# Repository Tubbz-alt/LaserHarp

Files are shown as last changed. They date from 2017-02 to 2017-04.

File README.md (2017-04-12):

# LaserHarp
The laser harp is a harp that uses lasers in place of strings. It is built to visually resemble a harp, consisting of a rectangular wooden frame and a set of 8 “strings”. Each “string” is a beam of an independent downward-pointing laser diode. A string is “plucked” by breaking the laser beam (most often with a hand, but it could be any object). There are sensors for each laser beam that detect when the beam has been broken. An Arduino board constantly reads out the sensors and if it detects an “pluck” event it will generate a sound. 

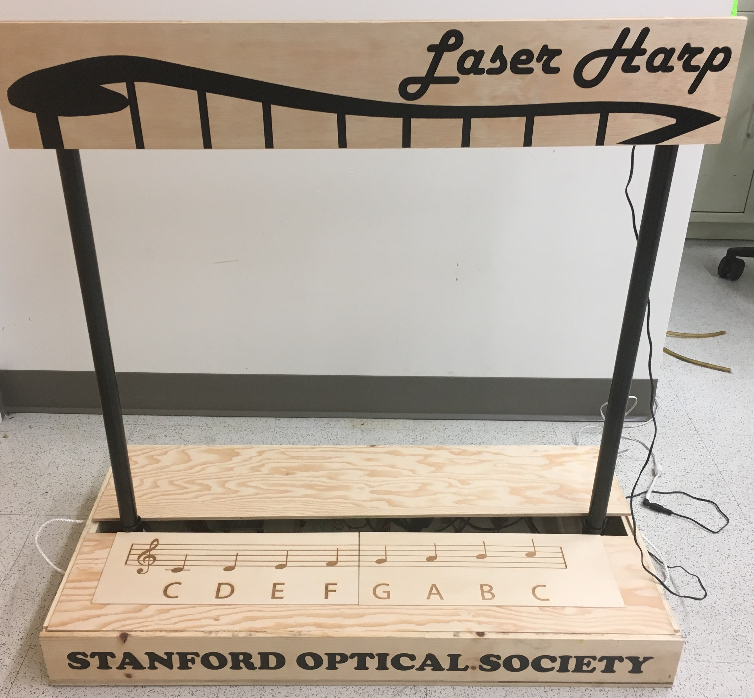
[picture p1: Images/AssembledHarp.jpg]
Assembled Laser Harp


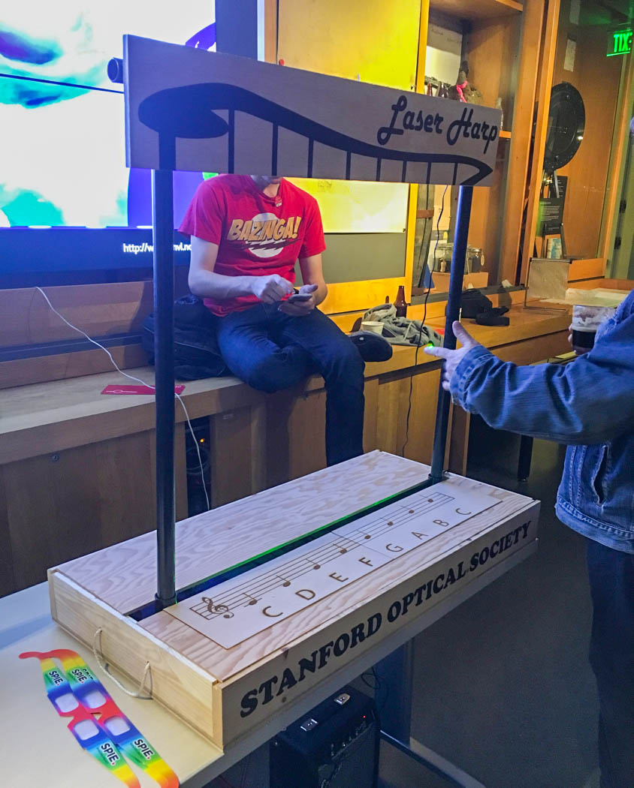
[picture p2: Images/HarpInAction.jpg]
Laser Harp in action


The laser harp works best in constant lighting conditions with the cover closed, as the laser beams will provide cleaner visual feedback when reflected off the harpist’s hands. Fog machines can also help visualize the beams but too much fog can trigger the harp sounds (the beam becomes too scattered and the sensors detect that as a broken beam).

It is a fun interactive demo suitable for all ages.

## [Assembly Instructions](https://github.com/mcleung/LaserHarp/blob/master/AssemblyInstructions.md)

## [Constructing your own Harp](https://github.com/mcleung/LaserHarp/blob/master/ConstructionInstructions.md)

# Credits
Thanks to everyone in the Stanford Optical Society for helping me build this, and to previous members who built the first version of the laser harp!

You can learn more about the Stanford Optical Society, and all of the work that we do at https://photons.stanford.edu

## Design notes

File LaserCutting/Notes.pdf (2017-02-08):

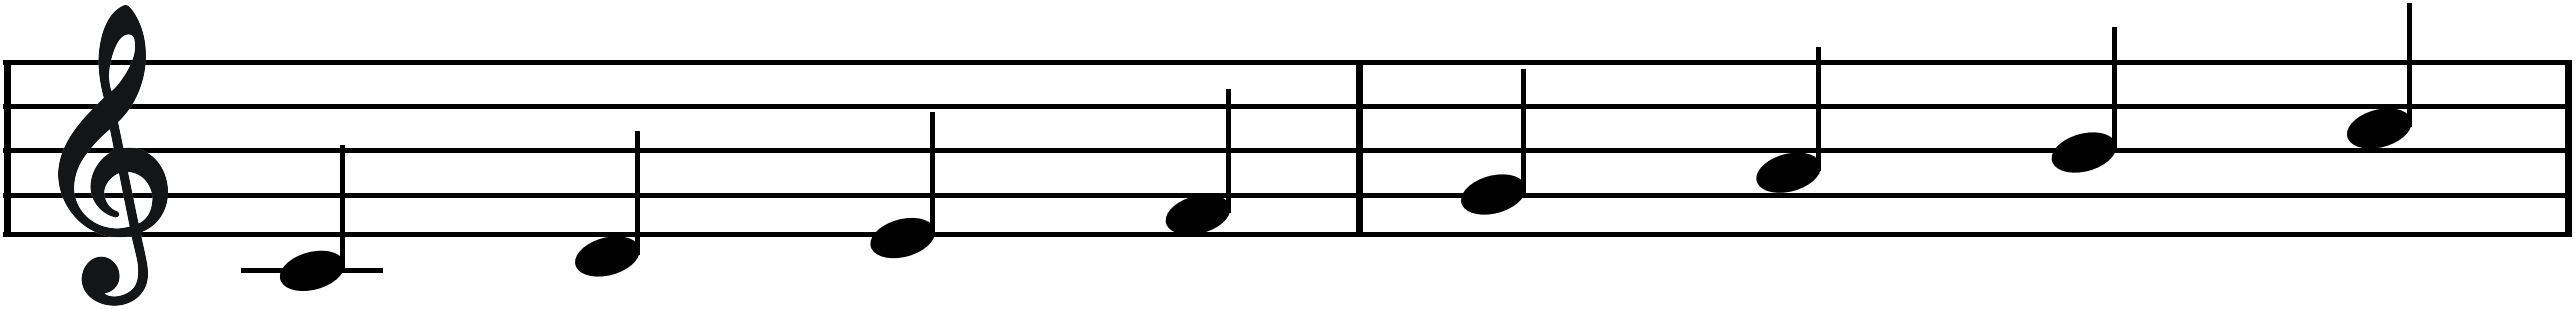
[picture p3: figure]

C D E F G A B C

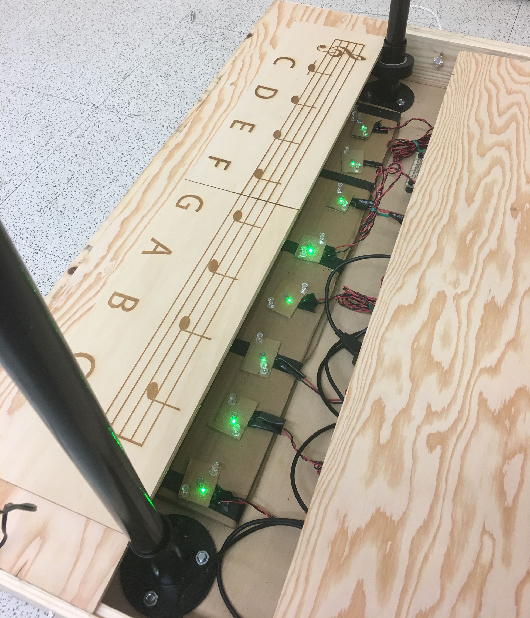
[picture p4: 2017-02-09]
Images/LaserDetectors.jpg

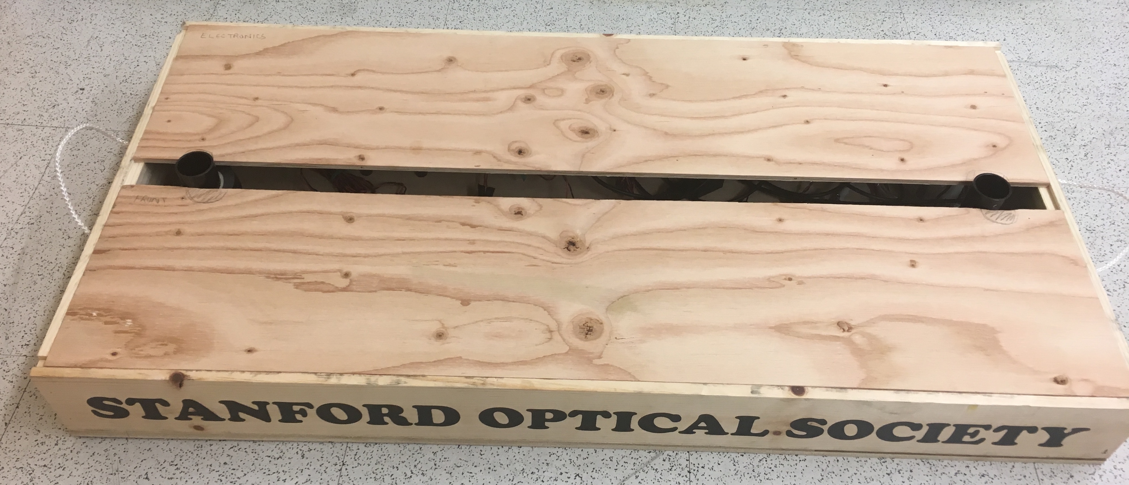
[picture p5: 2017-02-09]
Images/CompactHarp.jpg

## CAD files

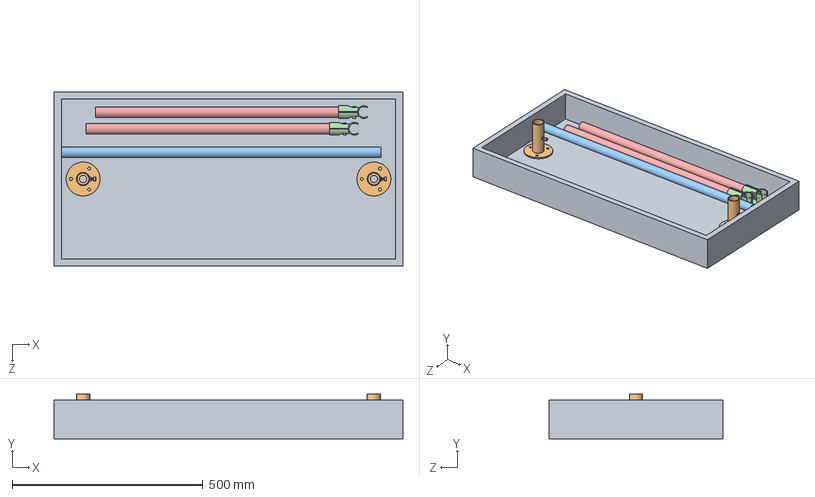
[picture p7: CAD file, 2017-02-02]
Mechanical/SolidWorks/1001-Transport.SLDASM
914.4 x 117.3 x 457.2 mm
6001-Base
6005-ClampFitting x 2
6020-PipeTop
6015-ClampOpen x 2
6010-PipeSide x 2

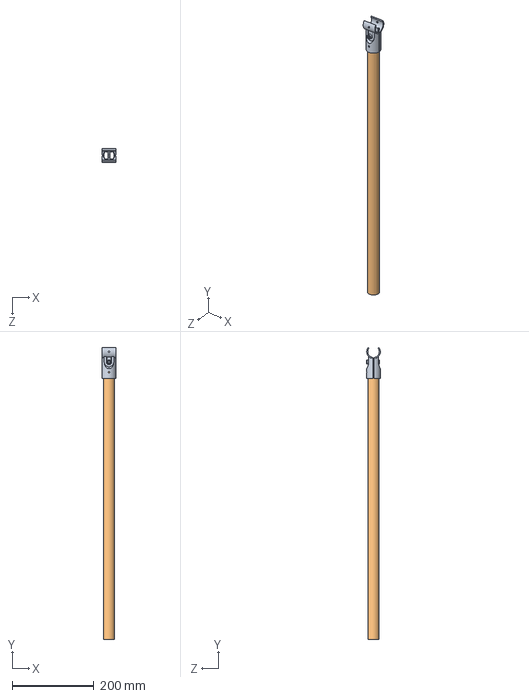
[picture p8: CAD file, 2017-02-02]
Mechanical/SolidWorks/1120-Post.SLDASM
33.5 x 713.4 x 33.8 mm
6015-ClampOpen
6010-PipeSide

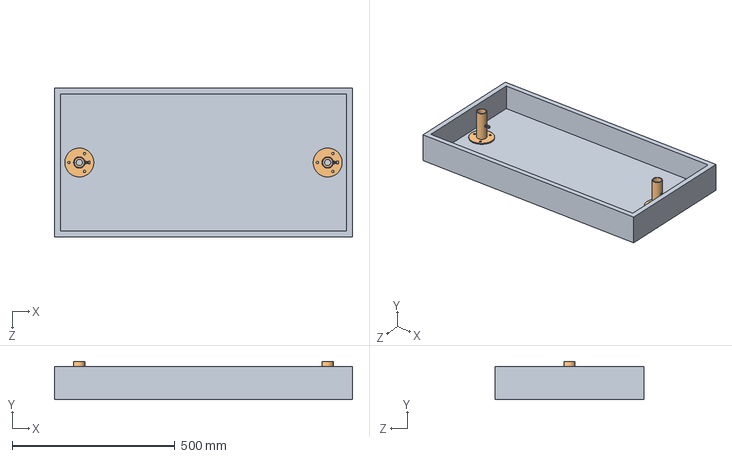
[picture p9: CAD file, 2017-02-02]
Mechanical/SolidWorks/1100-BaseAsm.SLDASM
914.4 x 117.3 x 457.2 mm
6001-Base
6005-ClampFitting x 2

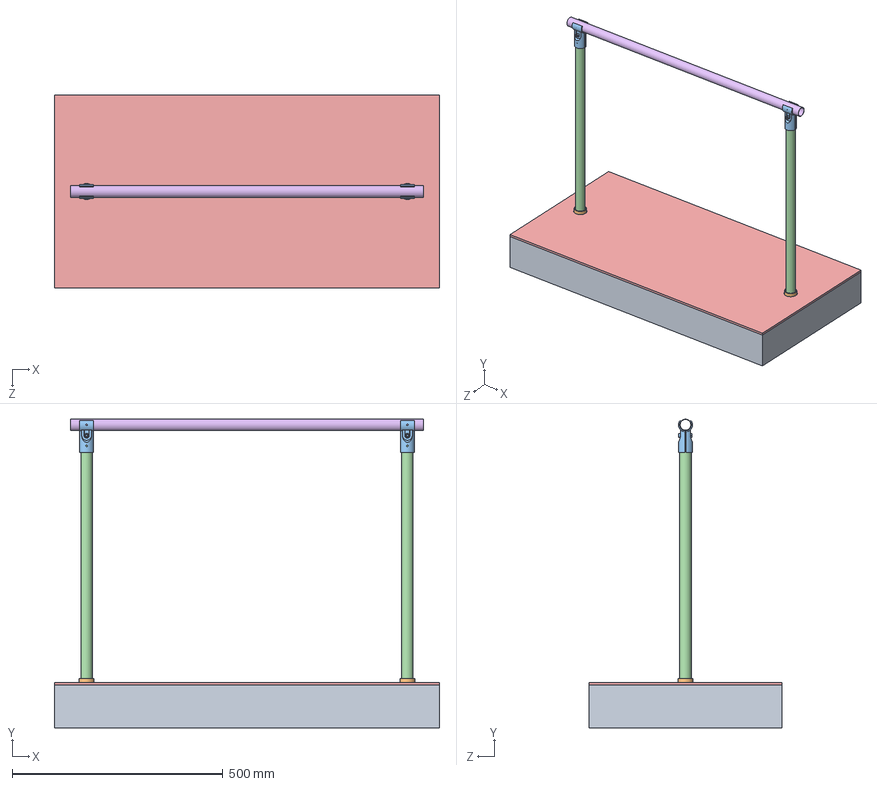
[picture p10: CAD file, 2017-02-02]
Mechanical/SolidWorks/1000-Assembled.SLDASM
914.4 x 733.5 x 457.2 mm
6001-Base
6005-ClampFitting x 2
6015-ClampOpen x 2
6010-PipeSide x 2
6003-BaseTop
6020-PipeTop

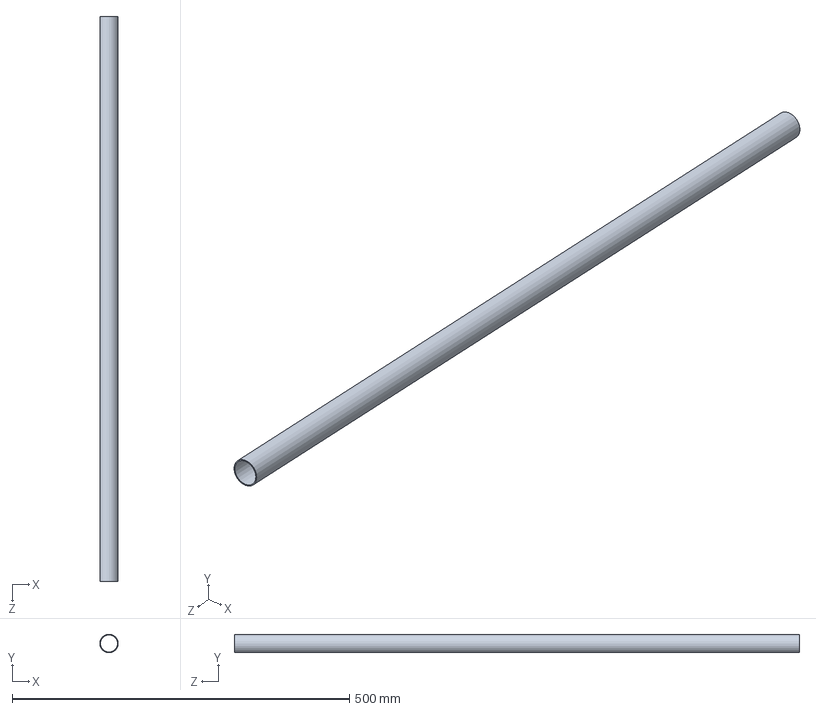
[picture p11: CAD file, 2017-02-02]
Mechanical/SolidWorks/1150-TopAsm.SLDASM
27.4 x 27.4 x 838.2 mm

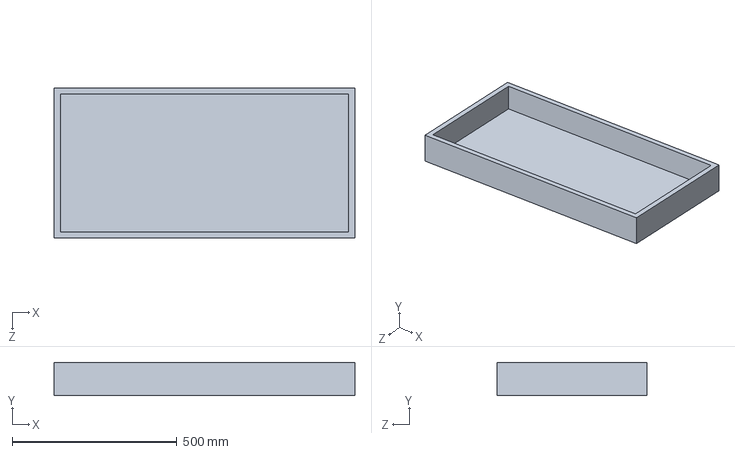
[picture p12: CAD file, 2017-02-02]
Mechanical/SolidWorks/6001-Base.SLDPRT
914.4 x 101.6 x 457.2 mm

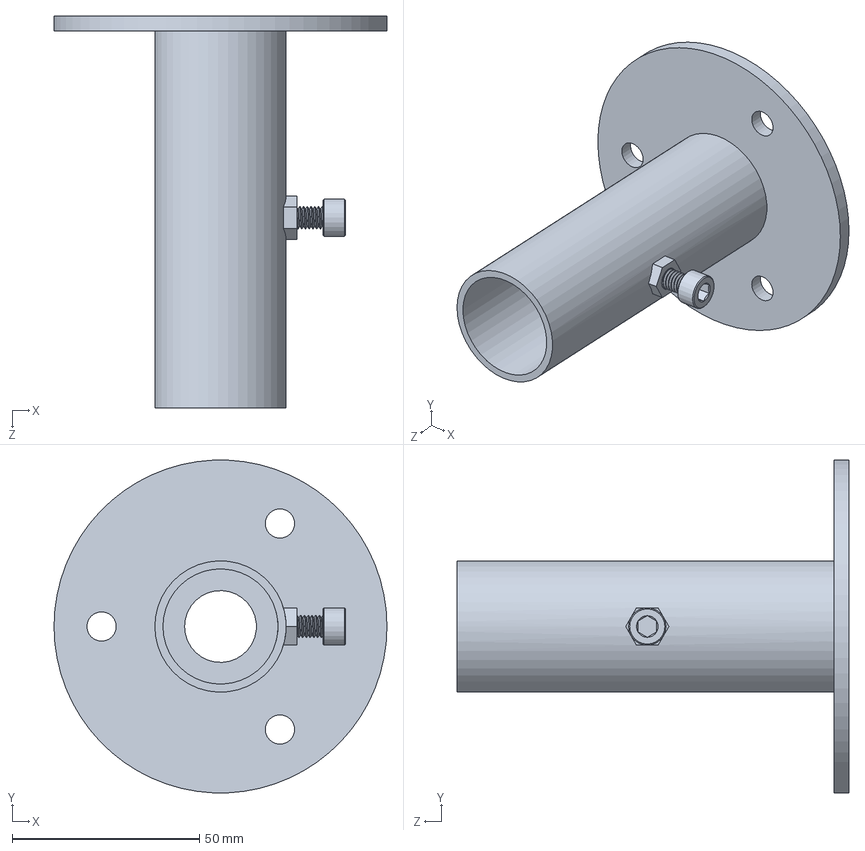
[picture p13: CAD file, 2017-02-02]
Mechanical/SolidWorks/6005-ClampFitting.SLDPRT
88.9 x 88.8 x 104.6 mm

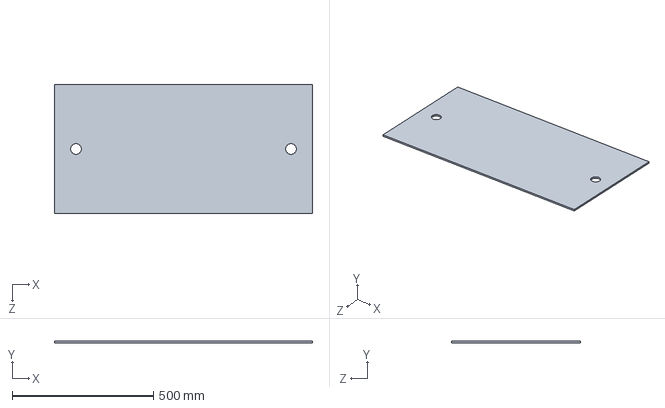
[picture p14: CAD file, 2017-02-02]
Mechanical/SolidWorks/6003-BaseTop.SLDPRT
914.4 x 6.35 x 457.2 mm

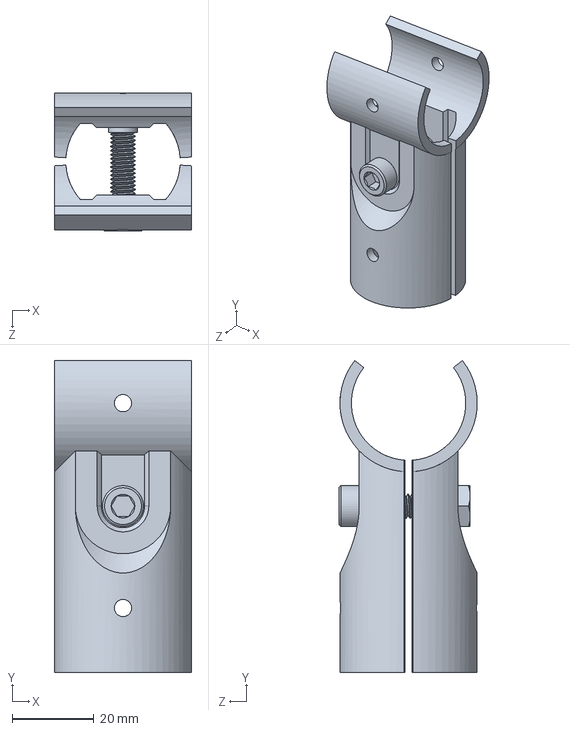
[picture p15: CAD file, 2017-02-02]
Mechanical/SolidWorks/6015-ClampOpen.SLDPRT
33.5 x 76.2 x 33.8 mm

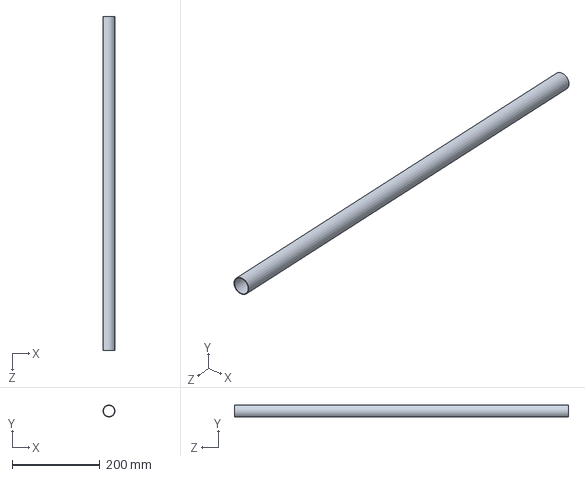
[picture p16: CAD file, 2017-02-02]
Mechanical/SolidWorks/6010-PipeSide.SLDPRT
27.4 x 27.4 x 762.0 mm

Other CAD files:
Mechanical/SolidWorks/6020-PipeTop.SLDPRT
Mechanical/SolidWorks/6023-TopPlate.SLDPRT

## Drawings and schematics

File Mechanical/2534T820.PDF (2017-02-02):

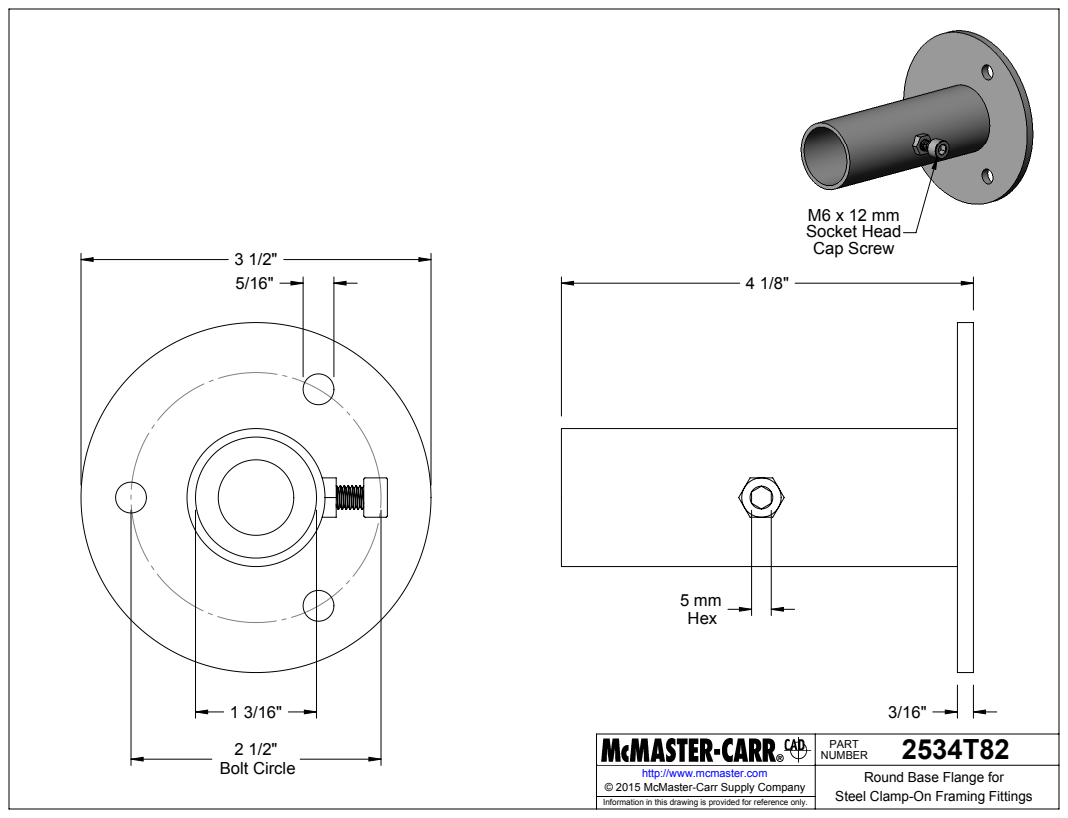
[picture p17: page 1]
2 1/2" Bolt Circle; M6 x 12 mm Socket Head Cap Screw

2534T82 PART NUMBER

http://www.mcmaster.com | Round Base Flange for Steel Clamp-On Framing Fittings © 2015 McMaster-Carr Supply Company

Information in this drawing is provided for reference only.

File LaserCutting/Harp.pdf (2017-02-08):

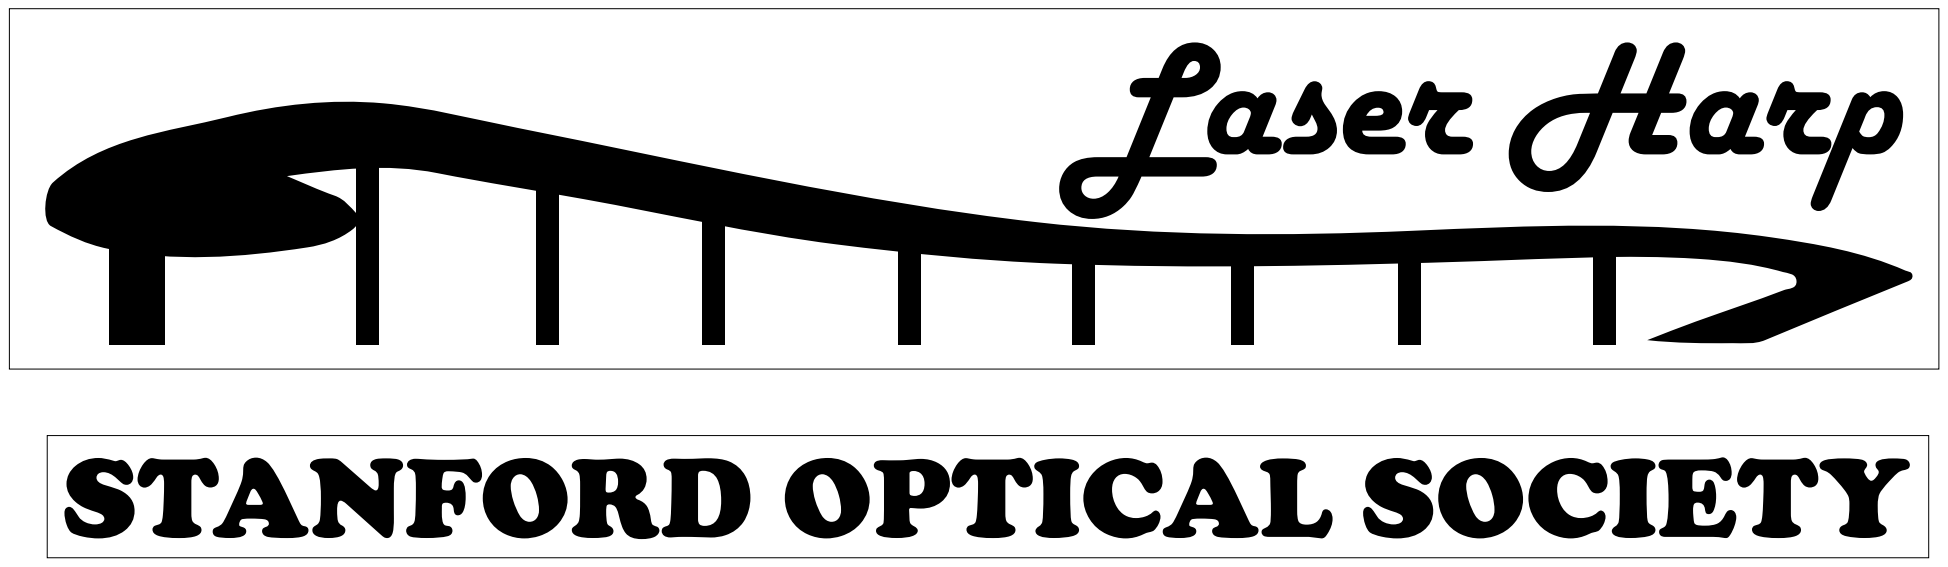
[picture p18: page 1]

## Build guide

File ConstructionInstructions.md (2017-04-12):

# Constructing your own harp
The material list and instructions below are for exactly replicating the laser harp built by Stanford OSA, but note that materials and processes can be changed to your liking. For example, the box is currently made from wood pieces commonly found at any hardware improvement store (e.g., Home Depot), but it could be replaced with any number of other materials and/or thicknesses.
Where applicable, we have included part numbers from specific manufacturers. 

## Materials Needed

### Wooden Frame
- Plywood:
  - 1 piece: 36 x 18 x 0.5 inch (base)
  - 1 piece: 33 x 10 x 0.5 inch (top crossbar)
  - 2 pieces: 35.5 x 8.5 x 0.25 inch (cover)
- Pine wood:
  - 2 pieces: 1 x 4 x 36 inch (long sidewalls)
  - 2 pieces: 1 x 4 x 16.5 inch (short sidewalls)
- Around 20 pieces: 1.5” wood screws to hold wood together
- Plastic-coated steel rail, 1 inch OD (McMaster Carr: [2534T13](https://www.mcmaster.com/#catalog/123/1964/=175omqx))
  - 2 pieces: 30 inches in length (side bars)
  - 1 piece: 32 inches in length (for crossbar)
- 2 pieces: round flange rail end (McMaster Carr: [2534T82](https://www.mcmaster.com/#catalog/123/1964/=175omfq))
- 2 pieces: open tee rail connector (McMaster Carr: [2534T22](https://www.mcmaster.com/#catalog/123/1964/=175omb7))
- 6 pieces: Carriage bolts and nuts (McMaster Carr: [93180A220](https://www.mcmaster.com/#carriage-bolts/=1760sma))
- 2 pieces: Routing clamps (McMaster Carr: [8874T43](https://www.mcmaster.com/#pipe-routing-clamps/=1760tv2))
- Wood glue

Note: decorations are made using a laser cutter and vinyl cutter

### Electronics
- 8 pieces: 5mW 532nm laser diodes (color is not important, but they should operate on 5V power supply. We used [these ones](https://m.dhgate.com/product/50mw-532nm-green-laser-diode-module-line/158930720.html))
- 8 pieces: Routing Clamps or other mounting hardware to attach lasers onto the crossbar. (McMaster Carr: [8874T14](https://www.mcmaster.com/#pipe-routing-clamps/=1760xm5))
- 16 pieces: screws for attaching conduit straps (should not be thicker than the crossbar, we used ⅜)
- Power supply for the lasers. We recommend a 1.5 to 2A supply (each laser uses ~100mA of power; we assume: 8 * 100mA + safety factor (Digikey: [993-1296-ND](https://www.digikey.com/product-detail/en/phihong-usa/PSC15A-050/993-1296-ND/5247140))
- Arduino Nano v3 (Digikey: [1050-1001-ND](https://www.digikey.com/product-detail/en/arduino/A000005/1050-1001-ND/2638989))
- MP3/audio board compatible with the Arduino (Gravitech: [MP3-4NANO](http://www.gravitech.us/mp3pladforar.html))
- Breadboard
- 8 pieces: photo-resistors (SparkFun: [SEN-09088](https://www.sparkfun.com/products/9088))
- 8 pieces: 10kOhm resistors
- USB power supply, including cable (used to power the arduino + audio board)
- Audio cable (3.5mm male to male)
- Guitar amp with a 3.5mm line in port
- Various wires to connect everything
- Electrical tape
- Cardboard
- Push pins

## Constructing the wooden frame

Below is an image from the 3D modeling of the wooden frame. The files can be find in the links at the end of the document. 
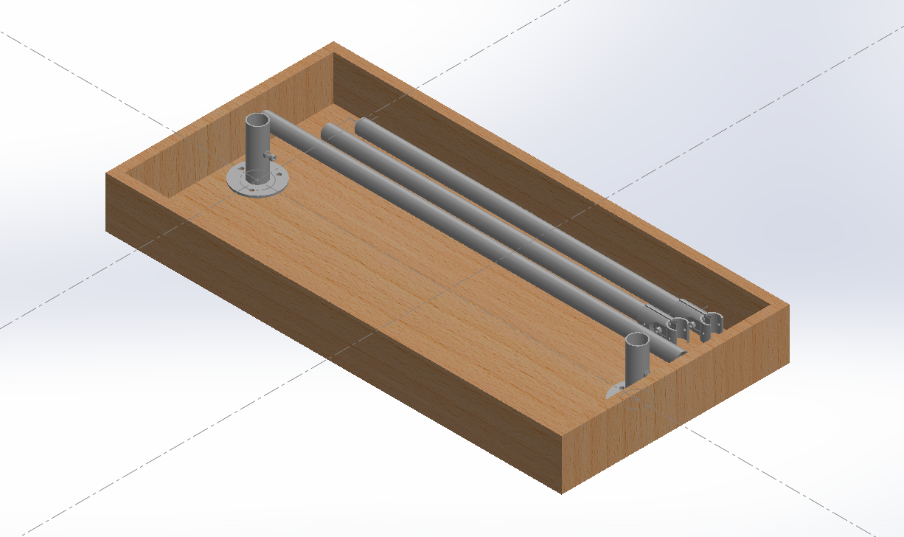
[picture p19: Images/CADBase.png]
CAD Base


1. Cut all wooden pieces to the sizes specified in the materials list.
2. Create a 0.25 x 0.25 inch notch in each sidewall so that the top cover piece fits nicely inside.
3. Use wood glue to attached the side walls to the base piece.
Secure each side wall to the base with screws (4 screws for the long sides and 2 screws for the short sides).
4. Using the carriage nuts and bolts attach the rail ends to the base of the box (centered in the box and separated by 30 inches).
5. Attach open tee rail connectors to the 30 inch pieces of rail. 
6. Fix the longer rail (32 inches) to the plywood used for the crossbar using conduit straps. 

For decorations (all files are available in the link at the end of the document):
1. Laser cut the staff pattern onto the sheet wood. If the bed of the laser cutter cannot fit the entire piece then you can split the staff into two parts. This is what we did for our laser harp. 
2. Vinyl cut the patterns for the top of the laser harp and affix to the crossbar. 

Notes:
- All the rail pieces, including the tee on the side bars, should be sized to fit within the box.
- The cover simply lays on top of the box. Alternatively, the top piece could be screwed into position or hinges could be used. 

## Constructing the software
  The latest version of the Arduino code is found on this [Github repository](https://github.com/mcleung/LaserHarp/tree/master/Arduino/LaserHarp). If you have any changes or suggestions, please let us know so we can update it!

## Constructing the electronics
1. Upload Arduino code found on this [Github repository](https://github.com/mcleung/LaserHarp/tree/master/Arduino/LaserHarp).

2. Connect Arduino onto the MIDI shield.

3. Connect midi shield output to speakers.

4. Evenly space and secure all lasers to the crossbar using conduit straps. We found that something between 1.5 to 2.5 inches works well.

5. Solder all the laser power supplies in parralel, and connect to the 5V 2A supply.

6. Affix each photoresistor to a small piece of cardboard.

7. Photoresistors should be connected to the Arduino as active low (pull-up) sensors. They should be wired as follows. 5V supply - 10k resistor(or other pull up resistor) - wire connecting back to Analog input - photoresistor - ground.

8. Turn on the lasers by connecting the power supply, and align detectors on cardboard piece.

9. Using the push pins, attached the cardboard/photoresistor to  larger piece of cardboard. The push pins give the flexibility to move the photoresistors for alignment with the lasers. 
  Beware! Avoid staring into the laser or direct reflections. Remove all jewlery and other shiny accessories.

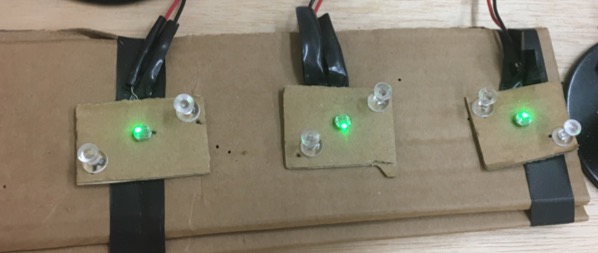
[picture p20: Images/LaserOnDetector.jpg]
Laser aligned on photoresistor


Notes:
  The chip on the audio board does not just support MP3 but also synthesizing sound based on MIDI commands. We are generating MIDI signals with the Arduino and playing them with the audio board.

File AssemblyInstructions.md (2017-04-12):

# Assembly Instructions

## Materials required

Laser Harp box containing electronics and power supply (See image)

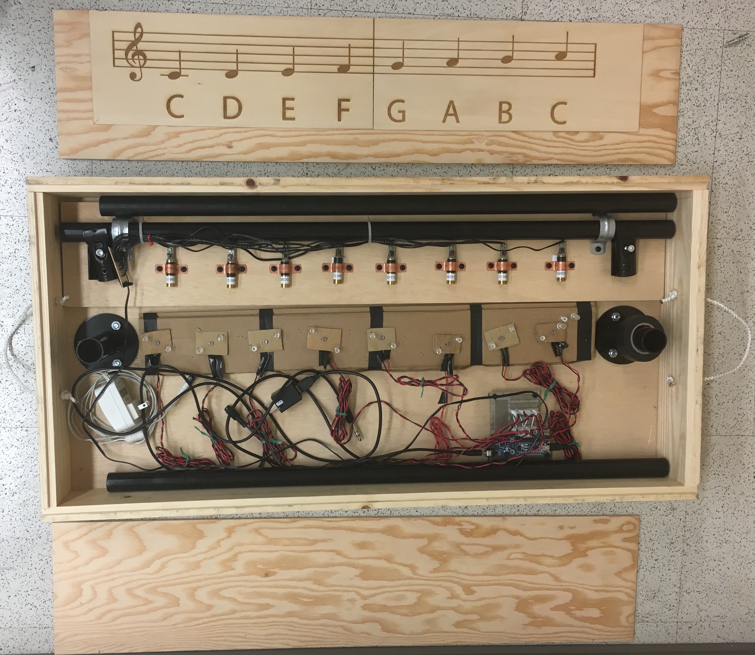
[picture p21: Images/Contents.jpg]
Laser Harp Box


External speakers (or Guitar Amplifier)

## Setup and Operation

Note: Be sure to set up the laser harp under the lighting conditions where it will be played to ensure that the sensors accurately detect a beam break activity. 

1. Open the laser harp box to expose the contents.

2. Inset two metal posts into the post holders, and tighten the screws (hand tight).
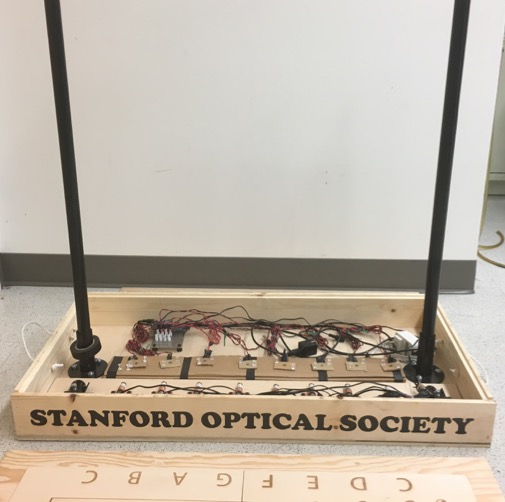
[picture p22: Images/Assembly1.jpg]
Assembly of posts


3. Remove the laser crossbar

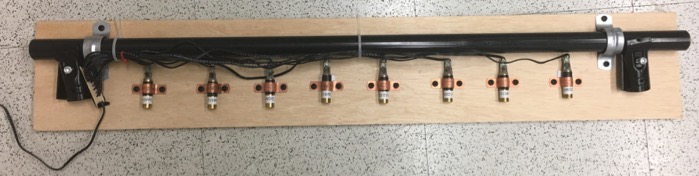
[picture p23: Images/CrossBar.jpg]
Crossbar


4. Place the cross bar into the posts

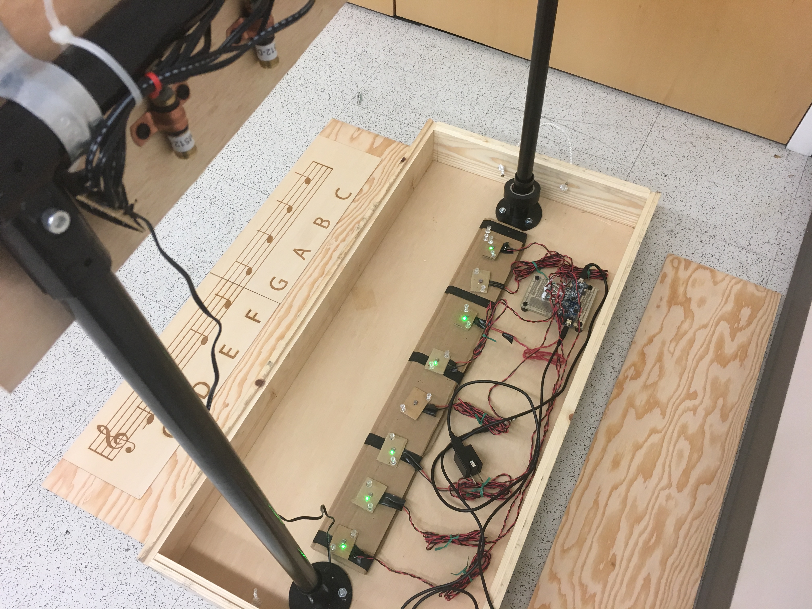
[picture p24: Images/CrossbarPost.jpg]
CrossbarPost


5. Connect the laser diodes’ power supply so that the lasers turn on

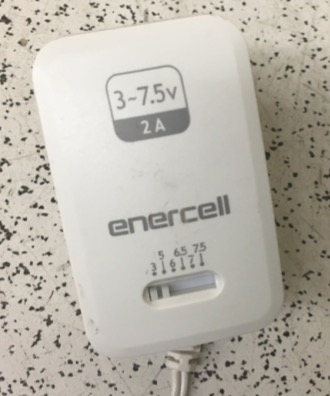
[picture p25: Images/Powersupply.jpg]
Powersupply


6. Adjust the photo-resistor positions such that the lasers are aligned (i.e., the laser beam overlaps the photo-resistor).

Laser aligned on photoresistor

7. Connect the Arduino to the speaker.

8. Turn on the speaker.

9. Connect Arduino to power supply.

10. The Arduino will go through an auto-threshold adjustment code to determine the right threshold to trigger. 
This should take 10-15 seconds, and will play a chord when it is ready.

11. Replace cover pieces onto harp box.

12. Play. If external lighting changes, reset the Arduino.

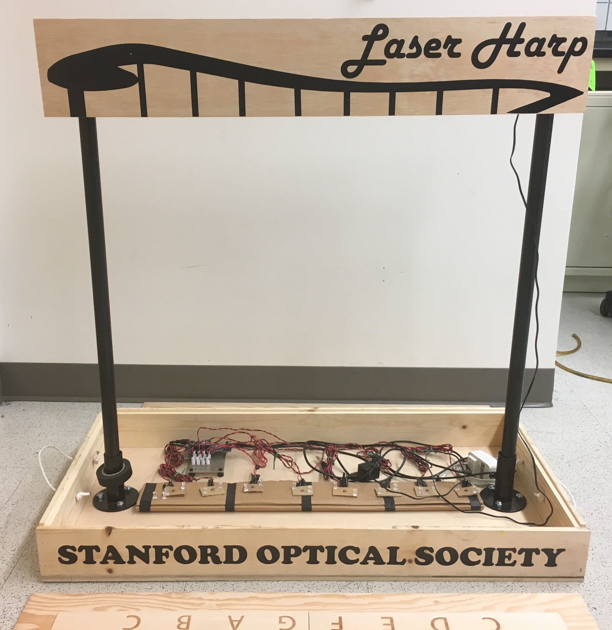
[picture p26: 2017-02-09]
Images/AssembledOpenHarp.jpg

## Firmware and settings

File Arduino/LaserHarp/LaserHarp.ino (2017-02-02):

/*

   File:     MP3_Shield_RealtimeMIDI.ino
   Author:   Michael Leung
             Adapted from Nickolas Tezak and Matthias Neeracher

   This code is in the public domain, with the exception of the contents of sVS1053b_Realtime_MIDI_Plugin.

   The code is based on Nathan Seidle's Sparkfun Electronics example code for the Sparkfun
   MP3 Player and Music Instrument shields and and VS1053 breakout board.

   http://www.sparkfun.com/Code/MIDI_Example.pde
   http://dlnmh9ip6v2uc.cloudfront.net/datasheets/Dev/Arduino/Shields/VS_Shield_Example.zip

        Spark Fun Electronics 2011
        Nathan Seidle

        This code is public domain but you buy me a beer if you use this and we meet someday (Beerware license).

   THEORY OF OPERATIONS

   The VS1053b has two ways of playing MIDI: One method is that you simply send a Standard MIDI level 0 file through
   SPI, and the chip will play it. This works exactly the same way as MP3 mode and will not be discussed further here.
   The other method is that the VS1053b has a "Real Time MIDI mode", in which it will instantly execute MIDI commands
   sent to it through either the UART or SPI.

   Real Time MIDI mode can be enabled with two different methods, controlled by USE_GPIO_INIT
    (1) Setting GPIO1 to HIGH (which is hardwired in the Sparkfun Music Instrument shield, and can be done through
        pin 4 in the MP3 Player Shield)
    (0) Sending a small software patch through SPI.

   MIDI data can be sent with two different methods as well, controlled by USE_SPI_MIDI
    (0) Through a (software) serial connection on pin 3, at 31250 baud
    (1) Through SPI, at an arbitrary data rate. For SPI, each byte of MIDI data needs to be prefixed by a 0 byte
        (The V1053b data sheet erroneously states that the padding should be a 0xFF byte).

   Both initialization methods and both transmission methods can be selected through the #defines below. Out of the box,
   it probably makes most sense to enable real time MIDI through pin 4, and send serial data through pin 3, but if you
   want to cut the traces for pin 3 and 4 and use those pins for another purpose, the alternative methods may come in
   handy.
*/


#define USE_GPIO_INIT  0
#define USE_SPI_MIDI   1

#define THRESHSAM 50 // Used to determine threshold for strumming. Increase if light source has high variability.

#define NUMNOTES 8 // Define number of notes.

#define VERBOSE_DEBUG true // Use true to output to screen (over serial) for debugging

#define USE_PATCH_INIT  !USE_GPIO_INIT
#define USE_SERIAL_MIDI !USE_SPI_INIT
#define USE_SPI         (USE_SPI_MIDI||USE_PATCH_INIT)

#if USE_SPI
#include <SPI.h>
#endif
#if USE_SERIAL_MIDI
#include <SoftwareSerial.h>
SoftwareSerial midiSerial(2, 3); // Soft TX on 3, RX not used (2 is an input anyway, for VS_DREQ)
#endif


// NOTE: We're using this MP3-MIDI Converter available at http://www.gravitech.us/mp3pladforar.html
// The breakout board contains the VS1053B chip. (Abbreviated VS for the remainder of code)
// Pinout for MP3 Converter:
// D2: MP3-DREQ
// D3: MIDI-RX (optional via jumper)
// D4: Micro-SD chip select
// D6: MP3 chip select
// D7: MP3-DCS
// D8: MP3-RST
// D11: SPI MOSI
// D12: SPI MISO
// D13: SPI SCK

#if USE_SPI
#define VS_XCS    6 // Control Chip Select Pin (for accessing SPI Control/Status registers)
#define VS_XDCS   7 // Data Chip Select / BSYNC Pin
#define VS_DREQ   2 // Data Request Pin: Player asks for more data
#endif
#if USE_GPIO_INIT
#define VS_GPIO1  4  // Mode selection (0 = file / 1 = real time MIDI)
#endif

#define VS_RESET  8 //Reset is active low

// import instrument definitions
#include "vs1053midi.h"


#define INSTRUMENT instr_orchestral_harp
//#define INSTRUMENT instr_marimba
//#define INSTRUMENT instr_guitar_harmonics
//#define INSTRUMENT instr_harpsichord
//#define INSTRUMENT instr_acoustic_grand_piano

unsigned short offset = 60;
unsigned short on_vel = 100;
unsigned short off_vel = 10;
unsigned short volume = 127; // Max volume is 127

const unsigned short notes[NUMNOTES] = {0, 2, 4, 5, 7, 9, 11, 12};

int counter = 0;
#define THRESHMIN 15

// Data used by MIDI
boolean chord_plucked[NUMNOTES] = {false, false, false, false, false, false, false, false};
boolean status_changed[NUMNOTES] = {false, false, false, false, false, false, false, false};

// Structure for holding sensor data
struct lightSensor {
  int curSample;
  int prevSample;
  int pinNum;
  int thresh;
};

// Array of Structure, for convenient indexing of sensors
lightSensor sensorArray[8];
int curSampleTemp;

// Determines the threshold for each sensor
void setupThresh() {
  // Buffer for storing a sequence of sensor measurements. It will be used to set threshold for each sensor at setup.
  //delay(10); // Increase this  (1000 = 1 second) if lasers turn on at the same time as arduino to give them time to stabilize.
  float threshMeas[THRESHSAM];
  float totalVal, mean, var, std;
  for (int note = 0; note < NUMNOTES; note++) {

    totalVal = 0;
    for (int nn = 0; nn < THRESHSAM; nn++) {
      threshMeas[nn] = (float) analogRead(sensorArray[note].pinNum);
      totalVal += threshMeas[nn];
      delay(1);
    }
    mean = totalVal / THRESHSAM;
    var = 0;
    for (int r = 0; r < THRESHSAM; r++) {
      var += pow(threshMeas[r] - mean, 2);
    }
    var = var / THRESHSAM;
    std = sqrt(var);

    sensorArray[note].thresh = max((int) (6 * std), THRESHMIN);

#if VERBOSE_DEBUG
    Serial.print(mean);
    Serial.print(" ");
    Serial.print(var);
    Serial.print(" ");
    Serial.print(std);
    Serial.print(" DONE \n");
#endif
  }
}


// Iterate through all sensors to determine if any of the sensors have been triggered.
// It uses a very rudimentary scheme for detecting laser blocking, by comparing it to the last measurement.
// NOTE: This scheme could be broken if someone was to very slowly move their hand over the detector.
//
// The value of chord_plucked[kk] should always reflect the current sensor readout, true for blocked laser
// the value of status_changed should only be updated to true if the current sensor readout and the last sensor are different,
// i.e., when the value of chord_plucked[kk] is actually being changed.
void readSensors() {
  for (int note = 0; note < NUMNOTES; note++) {
    curSampleTemp = analogRead(sensorArray[note].pinNum);
    if (curSampleTemp > sensorArray[note].prevSample + sensorArray[note].thresh) {
      chord_plucked[note] = true;
      status_changed[note] = true;
    }
    else if (curSampleTemp < sensorArray[note].prevSample - sensorArray[note].thresh) {
      chord_plucked[note] = false;
      status_changed[note] = true;
    }
    sensorArray[note].prevSample = sensorArray[note].curSample;
    sensorArray[note].curSample = curSampleTemp;
  }
  delay(10);
}


// Set the instrument of the first channel.
// We are currently using only one MIDI channel.
// We could easily change this.
void setupMidi() {
  int kk = 0;
  //  for(kk = 0; kk < 8; kk=kk+2){
  talkMIDI(0xB0 | kk, 0x00, 0x79); // Default bank GM1
  talkMIDI(0xB0 | kk, 0x07, volume); //0xB0 is channel message, set channel volume to near max (127)
  talkMIDI(0xC0 | kk, INSTRUMENT, 0); //Set instrument number. 0xC0 is a 1 data byte command
  //  }
}


void playChords() {
  // play sounds
  for (int note = 0; note < NUMNOTES; note++) {
    if (status_changed[note]) {
      if (chord_plucked[note]) {
        noteOn(0, notes[note] + offset, on_vel);
#if VERBOSE_DEBUG
        Serial.print("Playing Note:");
        Serial.println(note, DEC);
#endif
      } else {
        noteOff(0, notes[note] + offset, off_vel);
#if VERBOSE_DEBUG
        Serial.print("Stopping Note:");
        Serial.println(note, DEC);
#endif
      }
      status_changed[note] = false;
    }
  }
}


#if USE_PATCH_INIT
//Write to VS10xx register
//SCI: Data transfers are always 16bit. When a new SCI operation comes in
//DREQ goes low. We then have to wait for DREQ to go high again.
//XCS should be low for the full duration of operation.
void VSWriteRegister(unsigned char addressbyte, unsigned char highbyte, unsigned char lowbyte) {
  while (!digitalRead(VS_DREQ)) ; //Wait for DREQ to go high indicating IC is available
  digitalWrite(VS_XCS, LOW); //Select control

  //SCI consists of instruction byte, address byte, and 16-bit data word.
  SPI.transfer(0x02); //Write instruction
  SPI.transfer(addressbyte);
  SPI.transfer(highbyte);
  SPI.transfer(lowbyte);
  while (!digitalRead(VS_DREQ)) ; //Wait for DREQ to go high indicating command is complete
  digitalWrite(VS_XCS, HIGH); //Deselect Control
}


// Plugin to put VS10XX into realtime MIDI mode
// Originally from http://www.vlsi.fi/fileadmin/software/VS10XX/vs1053b-rtmidistart.zip
// Permission to reproduce here granted by VLSI solution.
//
const unsigned short sVS1053b_Realtime_MIDI_Plugin[28] = { /* Compressed plugin */
  0x0007, 0x0001, 0x8050, 0x0006, 0x0014, 0x0030, 0x0715, 0xb080, /*    0 */
  0x3400, 0x0007, 0x9255, 0x3d00, 0x0024, 0x0030, 0x0295, 0x6890, /*    8 */
  0x3400, 0x0030, 0x0495, 0x3d00, 0x0024, 0x2908, 0x4d40, 0x0030, /*   10 */
  0x0200, 0x000a, 0x0001, 0x0050,
};


void VSLoadUserCode(void) {
  int i = 0;
  while (i < sizeof(sVS1053b_Realtime_MIDI_Plugin) / sizeof(sVS1053b_Realtime_MIDI_Plugin[0])) {
    unsigned short addr, n, val;
    addr = sVS1053b_Realtime_MIDI_Plugin[i++];
    n = sVS1053b_Realtime_MIDI_Plugin[i++];
    while (n--) {
      val = sVS1053b_Realtime_MIDI_Plugin[i++];
      VSWriteRegister(addr, val >> 8, val & 0xFF);
    }
  }
}
#endif


// Setup code
// This code runs one upon initialization
void setup() {

#if VERBOSE_DEBUG
  Serial.begin(115200); //Use serial for debugging
  Serial.println("\n******\n");
  Serial.println("MP3 Shield for LaserHarp");
  Serial.println("Michael Leung, Stanford Optical Society");
  Serial.println("");
#endif

#if USE_SERIAL_MIDI
  midiSerial.begin(31250);
#endif

  //Initialize VS1053 chip
  pinMode(VS_RESET, OUTPUT);
  digitalWrite(VS_RESET, LOW); //Put VS1053 into hardware reset

#if USE_SPI
  pinMode(VS_DREQ, INPUT);
  pinMode(VS_XCS, OUTPUT);
  pinMode(VS_XDCS, OUTPUT);
  digitalWrite(VS_XCS, HIGH); //Deselect Control
  digitalWrite(VS_XDCS, HIGH); //Deselect Data
  //Setup SPI for VS1053
  pinMode(10, OUTPUT); //Pin 10 must be set as an output for the SPI communication to work
  SPI.begin();
  SPI.setBitOrder(MSBFIRST);
  SPI.setDataMode(SPI_MODE0);
  //From page 12 of datasheet, max SCI reads are CLKI/7. Input clock is 12.288MHz.
  //Internal clock multiplier is 1.0x after power up.
  //Therefore, max SPI speed is 1.75MHz. We will use 1MHz to be safe.
  SPI.setClockDivider(SPI_CLOCK_DIV16); //Set SPI bus speed to 1MHz (16MHz / 16 = 1MHz)
  SPI.transfer(0xFF); //Throw a dummy byte at the bus
#endif

  delay(1);
  digitalWrite(VS_RESET, HIGH); //Bring up VS1053

#if USE_PATCH_INIT
  VSLoadUserCode();
#else
  pinMode(VS_GPIO1, OUTPUT);
  digitalWrite(VS_GPIO1, HIGH);  // Enable real time MIDI mode
#endif

  sensorArray[0].pinNum = A0;
  sensorArray[1].pinNum = A1;
  sensorArray[2].pinNum = A2;
  sensorArray[3].pinNum = A3;
  sensorArray[4].pinNum = A4;
  sensorArray[5].pinNum = A5;
  sensorArray[6].pinNum = A6;
  sensorArray[7].pinNum = A7;
  setupMidi();
#if VERBOSE_DEBUG
  Serial.println("setupThresh");
#endif
  setupThresh();
#if VERBOSE_DEBUG
  Serial.println("Done!");
  for (int note = 0; note < NUMNOTES; note++) {
    Serial.print("Sensor threshold ");
    Serial.print(note);
    Serial.print(" ");
    Serial.println(sensorArray[note].thresh);
  }
#endif
}


void sendMIDI(byte data) {
#if USE_SPI_MIDI
  SPI.transfer(0);
  SPI.transfer(data);
#else
  midiSerial.write(data);
#endif
}


//Plays a MIDI note. Doesn't check to see that cmd is greater than 127, or that data values are less than 127
void talkMIDI(byte cmd, byte data1, byte data2) {
#if USE_SPI_MIDI
  // Wait for chip to be ready (Unlikely to be an issue with real time MIDI)
  while (!digitalRead(VS_DREQ))
  { } // wait, do nothing
  digitalWrite(VS_XDCS, LOW);
#endif
  sendMIDI(cmd);
  //Some commands only have one data byte. All cmds less than 0xBn have 2 data bytes
  //(sort of: http://253.ccarh.org/handout/midiprotocol/)
  if ( (cmd & 0xF0) <= 0xB0 || (cmd & 0xF0) >= 0xE0) {
    sendMIDI(data1);
    sendMIDI(data2);
  } else {
    sendMIDI(data1);
  }
#if USE_SPI_MIDI
  digitalWrite(VS_XDCS, HIGH);
#endif
}


// Send a MIDI note-on message.  Like pressing a piano key
// channel ranges from 0-15
void noteOn(byte channel, byte note, byte attack_velocity) {
  talkMIDI( (0x90 | channel), note, attack_velocity);
}


// Send a MIDI note-off message.  Like releasing a piano key
void noteOff(byte channel, byte note, byte release_velocity) {
  talkMIDI( (0x80 | channel), note, release_velocity);
}


void loop() {
  readSensors();
  playChords();
  //debugVerbose();
}


void debugVerbose() {
  for (int note = 0; note < NUMNOTES; note++) {
    Serial.print("sensor ");
    Serial.print(note);
    Serial.print("output: ");
    Serial.print(sensorArray[note].curSample);
    Serial.print(" ");
    Serial.print(sensorArray[note].prevSample - sensorArray[note].curSample);
    //Serial.print(analogRead(sensorArray[0].pinNum));
    Serial.print(" ");
    Serial.println(chord_plucked[note]);
  }

  // testing code
  chord_plucked[0] = true;
  status_changed[0] = true;
  playChords();
  delay(300);

  for (int kk = 0; kk < 7; kk++) {
    chord_plucked[kk] = false;
    status_changed[kk] = true;

    chord_plucked[kk + 1] = true;
    status_changed[kk + 1] = true;

    playChords();
    delay(300);
  }
  chord_plucked[7] = false;
  status_changed[7] = true;
  playChords();
  delay(1000);

  offset++;
  if (offset >= 100) offset = 22;
  // testing code end
}

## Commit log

2017-02-02 File Upload
    [1000-Assembled.SLDASM, 1001-Transport.SLDASM, 1100-BaseAsm.SLDASM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]
2017-04-12 Assembly Instructions!
